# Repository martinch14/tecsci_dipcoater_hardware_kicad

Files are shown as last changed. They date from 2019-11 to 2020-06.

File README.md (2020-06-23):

Diseño de Circuitos Integrados de la Carrera de Especialización en Sistemas Embebidos UBA

El siguiente diseño incluye el circuito integrado TMC5130 de la empresa TRINAMIC para el manejo de motores paso a paso
conectado con el módulo del microcontrolador ESP32D

Martin Abel Gambarotta
8vo Cohorte

Vista 3D:

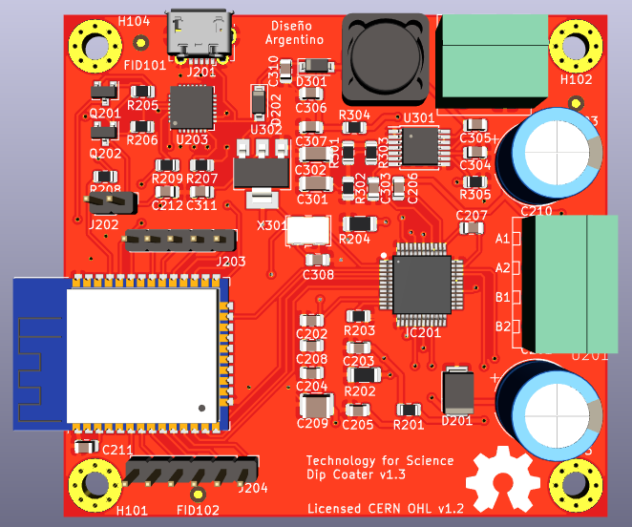
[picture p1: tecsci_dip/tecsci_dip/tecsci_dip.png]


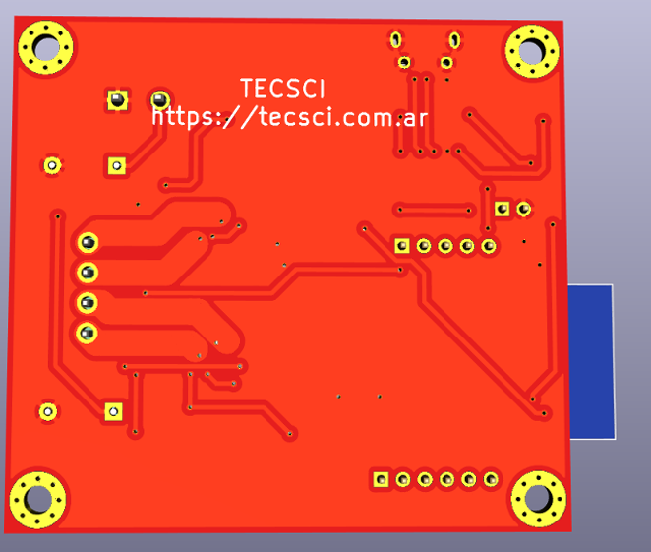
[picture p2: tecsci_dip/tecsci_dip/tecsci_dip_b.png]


Real: Fabricada y montada en Argentina Ernesto Mayer S.A. +  Asembli S.A.

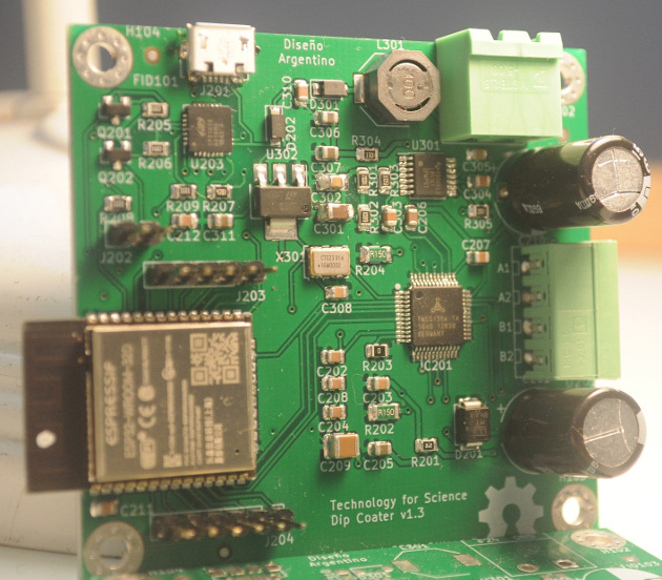
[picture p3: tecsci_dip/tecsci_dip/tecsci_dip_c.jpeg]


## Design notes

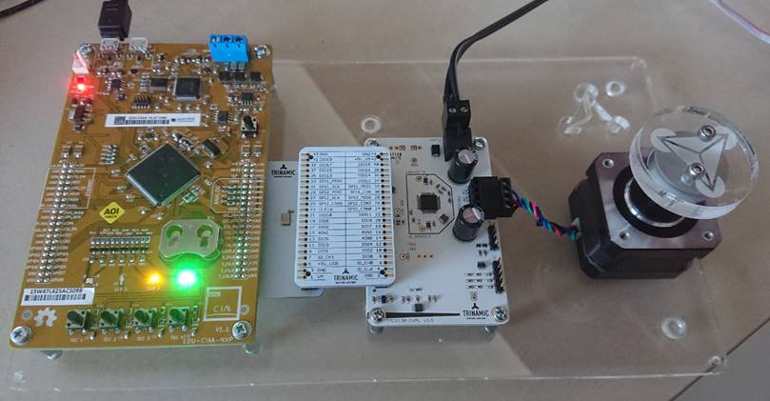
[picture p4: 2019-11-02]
info_propuesta/educiaa+tmc5130.jpg

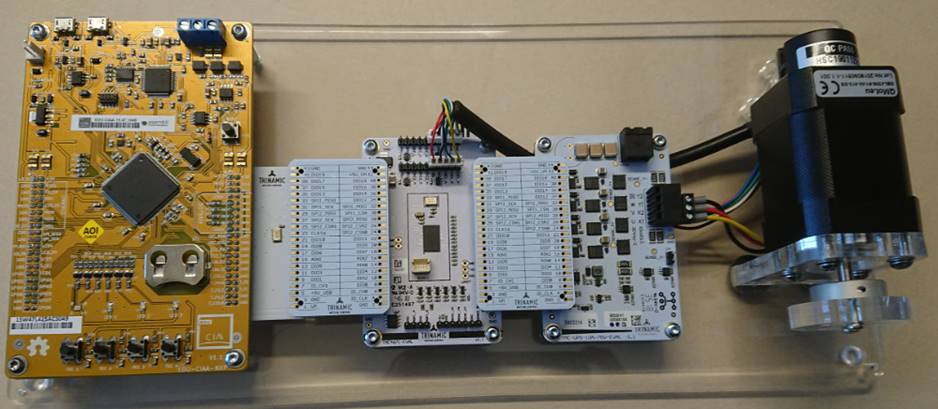
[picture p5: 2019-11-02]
info_propuesta/educiaa+tmc4671.jpg

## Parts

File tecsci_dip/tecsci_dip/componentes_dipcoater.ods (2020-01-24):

Qty | Reference(s) | Value | Footprint | digikey# | manf | manf#
2 | C201, C210 | 150uF/63V | Capacitor_THT:CP_Radial_D10.0mm_P7.50mm | P15406-ND | Panasonic Electronic Components | EEU-FR1J151
4 | C202, C204, C206, C208 | 100nF/50V | Capacitor_SMD:C_0805_2012Metric
1 | C203 | 470nF/16V | Capacitor_SMD:C_0805_2012Metric
1 | C205 | 4.7uF/16V | Capacitor_SMD:C_0805_2012Metric
2 | C207, C303 | 22nF/50V | Capacitor_SMD:C_0805_2012Metric
1 | C209 | 4.7uF/100V | Capacitor_SMD:C_1210_3225Metric
2 | C211, C212 | 0.1uF/10V | Capacitor_SMD:C_0805_2012Metric
1 | C301 | 2.2uF/100V | Capacitor_SMD:C_1206_3216Metric
1 | C302 | 100nF/100V | Capacitor_SMD:C_1206_3216Metric
1 | C304 | 1uF/50V | Capacitor_SMD:C_0805_2012Metric
1 | C305 | 10nF/10V | Capacitor_SMD:C_0805_2012Metric
3 | C306, C307, C311 | 10uF/10V | Capacitor_SMD:C_0805_2012Metric
1 | C308 | 10nF/16V | Capacitor_SMD:C_0805_2012Metric
1 | C310 | 100nF/10V | Capacitor_SMD:C_0805_2012Metric
1 | D201 | SMBJ43A | TMC5130-Eval_v15:SMB | SMBJ43AFSTR-ND | Taiwan Semiconductor Corporation | SMBJ43A
2 | D202, D301 | PMEG3020CEH | Diode_SMD:D_SOD-123 | 1727-3873-2-ND | Nexperia USA Inc. | PMEG3020EH,115
1 | IC201 | TMC5130 | TMC5130-Eval_v15:QFP50P900X900X113-49N_NOFID | 1460-1124-ND | Trinamic Motion Control GmbH | TMC5130A-TA
1 | J201 | USB_B_Micro | Connector_USB:USB_Micro-B_Molex-105017-0001 | WM1399CT-ND
1 | J202 | Boot | Connector_PinHeader_2.54mm:PinHeader_1x02_P2.54mm_Vertical | 5-146285-2-ND
1 | J203 | Conn_01x05 | Connector_PinHeader_2.54mm:PinHeader_1x05_P2.54mm_Vertical | SAM15242-ND
1 | J204 | Conn_01x06 | Connector_PinHeader_2.54mm:PinHeader_1x06_P2.54mm_Vertical | A121372-ND
1 | L301 | SRU8043 | Inductor_SMD:L_Bourns-SRU8043 | SRU8043-100YTR-ND | Bourns Inc. | SRU8043-100Y
1 | POWER_IN301 | POL_HEADER | TMC5130-Eval_v15:AKL349_02_POL | 277-1106-ND
2 | Q201, Q202 | S8050 | Package_TO_SOT_SMD:SOT-23 | MMSS8050-H-TPMSCT-ND
1 | R201 | 2R2/1% | Resistor_SMD:R_0805_2012Metric
2 | R202, R204 | 0R15/1% | Resistor_SMD:R_1206_3216Metric
1 | R203 | 0R/1% | Resistor_SMD:R_0805_2012Metric
2 | R205, R206 | 10K/1% | Resistor_SMD:R_0805_2012Metric
1 | R207 | 4.7K/1% | Resistor_SMD:R_0805_2012Metric
2 | R208, R209 | 1K/1% | Resistor_SMD:R_0805_2012Metric
1 | R301 | 30k/1% | Resistor_SMD:R_0805_2012Metric
1 | R302 | 6.8k/1% | Resistor_SMD:R_0805_2012Metric
1 | R303 | 150k/1% | Resistor_SMD:R_0805_2012Metric
1 | R304 | 3.3k/1% | Resistor_SMD:R_0805_2012Metric
1 | R305 | 2.2k/1% | Resistor_SMD:R_0805_2012Metric
1 | U201 | AKL182_04_POL_HEADER | TMC5130-Eval_v15:AKL169_04_POL | 277-1208-ND
1 | U202 | ESP32-WROOM-32D | RF_Module:ESP32-WROOM-32 | 1904-1023-2-ND
1 | U203 | CP2102N-A01-GQFN28 | Package_DFN_QFN:QFN-28-1EP_5x5mm_P0.5mm_EP3.35x3.35mm | 336-5890-1-ND
1 | U301 | Regulador_LM5161 | Package_SO:TSSOP-14-1EP_4.4x5mm_P0.65mm | 296-47791-2-ND | Texas Instruments | LM5161QPWPRQ1
1 | U302 | LD1117S33TR_SOT223 | Package_TO_SOT_SMD:SOT-223-3_TabPin2 | 497-1242-1-ND
1 | X301 | Oscillator_636L3C016M00000 | Oscillator:Oscillator_SMD_EuroQuartz_XO53-4Pin_5.0x3.2mm | CTX691CT-ND

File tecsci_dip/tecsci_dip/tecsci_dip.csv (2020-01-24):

Source: | /home/martin/Escritorio/KiCadProject/tecsci_dipcoater_github/tecsci_dip/tecsci_dip/tecsci_dip.sch
Date: | vie 24 ene 2020 11:53:21 -03
Tool: | Eeschema 5.1.4-e60b266~84~ubuntu18.04.1
Generator: | /usr/share/kicad/plugins/bom_csv_grouped_by_value.py
Component Count: | 62
Individual Components:
Item | Qty | Reference(s) | Value | LibPart | Footprint | Datasheet | digikey# | manf | manf#
 |  | C201 | 150uF/63V | Device:CP | Capacitor_THT:CP_Radial_D10.0mm_P7.50mm | ~ | P15406-ND | Panasonic Electronic Components | EEU-FR1J151
 |  | C202 | 100nF/50V | Device:C | Capacitor_SMD:C_0805_2012Metric | ~
 |  | C203 | 470nF/16V | Device:C | Capacitor_SMD:C_0805_2012Metric | ~
 |  | C204 | 100nF/50V | Device:C | Capacitor_SMD:C_0805_2012Metric | ~
 |  | C205 | 4.7uF/16V | Device:C | Capacitor_SMD:C_0805_2012Metric | https://api.kemet.com/component-edge/download/datasheet/C0805C475K4RACAUTO.pdf | 399-15711-2-ND | KEMET | C0805C475K4RACAUTO
 |  | C206 | 100nF/50V | Device:C | Capacitor_SMD:C_0805_2012Metric | ~
 |  | C207 | 22nF/50V | Device:C | Capacitor_SMD:C_0805_2012Metric | ~
 |  | C208 | 100nF/50V | Device:C | Capacitor_SMD:C_0805_2012Metric | ~
 |  | C209 | 4.7uF/100V | Device:C | Capacitor_SMD:C_1210_3225Metric | ~
 |  | C210 | 150uF/63V | Device:CP | Capacitor_THT:CP_Radial_D10.0mm_P7.50mm | ~ | P15406-ND | Panasonic Electronic Components | EEU-FR1J151
 |  | C211 | 0.1uF/10V | Device:C | Capacitor_SMD:C_0805_2012Metric | ~
 |  | C212 | 0.1uF/10V | Device:C | Capacitor_SMD:C_0805_2012Metric | ~
 |  | C301 | 2.2uF/100V | Device:C | Capacitor_SMD:C_1206_3216Metric | ~
 |  | C302 | 100nF/100V | Device:C | Capacitor_SMD:C_1206_3216Metric | ~
 |  | C303 | 22nF/50V | Device:C | Capacitor_SMD:C_0805_2012Metric | ~
 |  | C304 | 1uF/50V | Device:C | Capacitor_SMD:C_0805_2012Metric | ~
 |  | C305 | 10nF/10V | Device:C | Capacitor_SMD:C_0805_2012Metric | ~
 |  | C306 | 10uF/10V | Device:C | Capacitor_SMD:C_0805_2012Metric | ~
 |  | C307 | 10uF/10V | Device:C | Capacitor_SMD:C_0805_2012Metric | ~
 |  | C308 | 10nF/16V | Device:C | Capacitor_SMD:C_0805_2012Metric | ~
 |  | C310 | 100nF/10V | Device:C | Capacitor_SMD:C_0805_2012Metric | ~
 |  | C311 | 10uF/10V | Device:C | Capacitor_SMD:C_0805_2012Metric | ~
 |  | D201 | SMBJ43A | TMC5130-Eval_v15-eagle-import:SMBJ | TMC5130-Eval_v15:SMB | https://www.taiwansemi.com/products/datasheet/SMBJ%20SERIES_P1812.pdf | SMBJ43AFSTR-ND | Taiwan Semiconductor Corporation | SMBJ43A
 |  | D202 | PMEG3020CEH | tecsci_dip-cache:PMEG6010CEH | Diode_SMD:D_SOD-123 |  | 1727-3873-2-ND | Nexperia USA Inc. | PMEG3020EH,115
 |  | D301 | PMEG3020CEH | Diode:PMEG6010CEH | Diode_SMD:D_SOD-123 | https://assets.nexperia.com/documents/data-sheet/PMEG6010CEH_PMEG6010CEJ.pdf | 1727-3873-2-ND | Nexperia USA Inc. | PMEG3020EH,115
 |  | FID101 | Fiducial | Mechanical:Fiducial | Fiducial:Fiducial_1mm_Mask2mm | ~
 |  | FID102 | Fiducial | Mechanical:Fiducial | Fiducial:Fiducial_1mm_Mask2mm | ~
 |  | FID103 | Fiducial | Mechanical:Fiducial | Fiducial:Fiducial_1mm_Mask2mm | ~
 |  | H101 | MountingHole | Mechanical:MountingHole | MountingHole:MountingHole_3.2mm_M3_Pad_Via | ~
 |  | H102 | MountingHole | Mechanical:MountingHole | MountingHole:MountingHole_3.2mm_M3_Pad_Via | ~
 |  | H103 | MountingHole | Mechanical:MountingHole | MountingHole:MountingHole_3.2mm_M3_Pad_Via | ~
 |  | H104 | MountingHole | Mechanical:MountingHole | MountingHole:MountingHole_3.2mm_M3_Pad_Via | ~
 |  | IC201 | TMC5130 | TMC5130-Eval_v15-eagle-import:TMC5130 | TMC5130-Eval_v15:QFP50P900X900X113-49N_NOFID | https://www.trinamic.com/_scripts/download.php | 1460-1124-ND | Trinamic Motion Control GmbH | TMC5130A-TA
 |  | J201 | USB_B_Micro | Connector:USB_B_Micro | Connector_USB:USB_Micro-B_Molex-105017-0001 | ~ | WM1399CT-ND
 |  | J202 | Boot | Connector_Generic:Conn_01x02 | Connector_PinHeader_2.54mm:PinHeader_1x02_P2.54mm_Vertical | ~
 |  | J203 | Conn_01x05 | Connector_Generic:Conn_01x05 | Connector_PinHeader_2.54mm:PinHeader_1x05_P2.54mm_Vertical | ~
 |  | J204 | Conn_01x06 | Connector_Generic:Conn_01x06 | Connector_PinHeader_2.54mm:PinHeader_1x06_P2.54mm_Vertical | ~
 |  | L301 | SRU8043 | Ponchobrücke-cache:Device_L_Core_Ferrite | Inductor_SMD:L_Bourns-SRU8043 | https://www.bourns.com/docs/Product-Datasheets/SRU8043.pdf | SRU8043-100YTR-ND | Bourns Inc. | SRU8043-100Y
 |  | OSHWA101 | Logo_Open_Hardware_Small | Graphic:Logo_Open_Hardware_Small | Symbol:OSHW-Symbol_8.9x8mm_SilkScreen | ~
 |  | POWER_IN301 | POL_HEADER | TMC5130-Eval_v15-eagle-import:AKL_349_02_POL_HEADER | TMC5130-Eval_v15:AKL349_02_POL |  | 277-1106-ND
 |  | Q201 | S8050 | Transistor_BJT:S8050 | Package_TO_SOT_SMD:SOT-23 | http://www.unisonic.com.tw/datasheet/S8050.pdf | MMSS8050-H-TPMSCT-ND
 |  | Q202 | S8050 | Transistor_BJT:S8050 | Package_TO_SOT_SMD:SOT-23 | http://www.unisonic.com.tw/datasheet/S8050.pdf | MMSS8050-H-TPMSCT-ND
 |  | R201 | 2R2/1% | Device:R | Resistor_SMD:R_0805_2012Metric | ~
 |  | R202 | 0R15/1% | Device:R | Resistor_SMD:R_1206_3216Metric | ~
 |  | R203 | 0R/1% | Device:R | Resistor_SMD:R_0805_2012Metric | ~
 |  | R204 | 0R15/1% | Device:R | Resistor_SMD:R_1206_3216Metric | ~
 |  | R205 | 10K/1% | Device:R | Resistor_SMD:R_0805_2012Metric | ~
 |  | R206 | 10K/1% | Device:R | Resistor_SMD:R_0805_2012Metric | ~
 |  | R207 | 4.7K/1% | Device:R | Resistor_SMD:R_0805_2012Metric | ~
 |  | R208 | 1K/1% | Device:R | Resistor_SMD:R_0805_2012Metric | ~
 |  | R209 | 1K/1% | Device:R | Resistor_SMD:R_0805_2012Metric | ~
 |  | R301 | 30k/1% | Device:R | Capacitor_SMD:C_0805_2012Metric | ~
 |  | R302 | 6.8k/1% | Device:R | Resistor_SMD:R_0805_2012Metric | ~
 |  | R303 | 150k/1% | Device:R | Resistor_SMD:R_0805_2012Metric | ~
 |  | R304 | 3.3k/1% | Device:R | Resistor_SMD:R_0805_2012Metric | ~
 |  | R305 | 2.2k/1% | Device:R | Resistor_SMD:R_0805_2012Metric | ~
 |  | U201 | AKL182_04_POL_HEADER | TMC5130-Eval_v15-eagle-import:AKL182_04_POL_HEADER | TMC5130-Eval_v15:AKL169_04_POL |  | 277-1208-ND
 |  | U202 | ESP32-WROOM-32D | RF_Module:ESP32-WROOM-32D | RF_Module:ESP32-WROOM-32 | https://www.espressif.com/sites/default/files/documentation/esp32-wroom-32d_esp32-wroom-32u_datasheet_en.pdf | 1904-1023-2-ND
 |  | U203 | CP2102N-A01-GQFN28 | Interface_USB:CP2102N-A01-GQFN28 | Package_DFN_QFN:QFN-28-1EP_5x5mm_P0.5mm_EP3.35x3.35mm | https://www.silabs.com/documents/public/data-sheets/cp2102n-datasheet.pdf | 336-5890-1-ND
 |  | U301 | Regulador_LM5161 | Ponchobrücke-cache:Regulator_Controller_LM5161 | Package_SO:TSSOP-14-1EP_4.4x5mm_P0.65mm | http://www.ti.com/general/docs/suppproductinfo.tsp?distId=10 | 296-47791-2-ND | Texas Instruments | LM5161QPWPRQ1
 |  | U302 | LD1117S33TR_SOT223 | Regulator_Linear:LD1117S33TR_SOT223 | Package_TO_SOT_SMD:SOT-223-3_TabPin2 | http://www.st.com/st-web-ui/static/active/en/resource/technical/document/datasheet/CD00000544.pdf | 497-1242-1-ND
 |  | X301 | Oscillator_636L3C016M00000 | Ponchobrücke-cache:Oscillator_636L3C016M00000 | Oscillator:Oscillator_SMD_EuroQuartz_XO53-4Pin_5.0x3.2mm |  | CTX691CT-ND
Collated Components:
Item | Qty | Reference(s) | Value | LibPart | Footprint | Datasheet | digikey# | manf | manf#
1 | 2 | C201, C210 | 150uF/63V | Device:CP | Capacitor_THT:CP_Radial_D10.0mm_P7.50mm | ~ | P15406-ND | Panasonic Electronic Components | EEU-FR1J151
2 | 4 | C202, C204, C206, C208 | 100nF/50V | Device:C | Capacitor_SMD:C_0805_2012Metric | ~
3 | 1 | C203 | 470nF/16V | Device:C | Capacitor_SMD:C_0805_2012Metric | ~
4 | 1 | C205 | 4.7uF/16V | Device:C | Capacitor_SMD:C_0805_2012Metric | https://api.kemet.com/component-edge/download/datasheet/C0805C475K4RACAUTO.pdf | 399-15711-2-ND | KEMET | C0805C475K4RACAUTO
5 | 2 | C207, C303 | 22nF/50V | Device:C | Capacitor_SMD:C_0805_2012Metric | ~
6 | 1 | C209 | 4.7uF/100V | Device:C | Capacitor_SMD:C_1210_3225Metric | ~
7 | 2 | C211, C212 | 0.1uF/10V | Device:C | Capacitor_SMD:C_0805_2012Metric | ~
8 | 1 | C301 | 2.2uF/100V | Device:C | Capacitor_SMD:C_1206_3216Metric | ~
9 | 1 | C302 | 100nF/100V | Device:C | Capacitor_SMD:C_1206_3216Metric | ~
10 | 1 | C304 | 1uF/50V | Device:C | Capacitor_SMD:C_0805_2012Metric | ~
11 | 1 | C305 | 10nF/10V | Device:C | Capacitor_SMD:C_0805_2012Metric | ~
12 | 3 | C306, C307, C311 | 10uF/10V | Device:C | Capacitor_SMD:C_0805_2012Metric | ~
13 | 1 | C308 | 10nF/16V | Device:C | Capacitor_SMD:C_0805_2012Metric | ~
14 | 1 | C310 | 100nF/10V | Device:C | Capacitor_SMD:C_0805_2012Metric | ~
15 | 1 | D201 | SMBJ43A | TMC5130-Eval_v15-eagle-import:SMBJ | TMC5130-Eval_v15:SMB | https://www.taiwansemi.com/products/datasheet/SMBJ%20SERIES_P1812.pdf | SMBJ43AFSTR-ND | Taiwan Semiconductor Corporation | SMBJ43A
16 | 2 | D202, D301 | PMEG3020CEH | Diode:PMEG6010CEH | Diode_SMD:D_SOD-123 | https://assets.nexperia.com/documents/data-sheet/PMEG6010CEH_PMEG6010CEJ.pdf | 1727-3873-2-ND | Nexperia USA Inc. | PMEG3020EH,115
17 | 3 | FID101, FID102, FID103 | Fiducial | Mechanical:Fiducial | Fiducial:Fiducial_1mm_Mask2mm | ~
18 | 4 | H101, H102, H103, H104 | MountingHole | Mechanical:MountingHole | MountingHole:MountingHole_3.2mm_M3_Pad_Via | ~
19 | 1 | IC201 | TMC5130 | TMC5130-Eval_v15-eagle-import:TMC5130 | TMC5130-Eval_v15:QFP50P900X900X113-49N_NOFID | https://www.trinamic.com/_scripts/download.php | 1460-1124-ND | Trinamic Motion Control GmbH | TMC5130A-TA
20 | 1 | J201 | USB_B_Micro | Connector:USB_B_Micro | Connector_USB:USB_Micro-B_Molex-105017-0001 | ~ | WM1399CT-ND
21 | 1 | J202 | Boot | Connector_Generic:Conn_01x02 | Connector_PinHeader_2.54mm:PinHeader_1x02_P2.54mm_Vertical | ~
22 | 1 | J203 | Conn_01x05 | Connector_Generic:Conn_01x05 | Connector_PinHeader_2.54mm:PinHeader_1x05_P2.54mm_Vertical | ~
23 | 1 | J204 | Conn_01x06 | Connector_Generic:Conn_01x06 | Connector_PinHeader_2.54mm:PinHeader_1x06_P2.54mm_Vertical | ~
24 | 1 | L301 | SRU8043 | Ponchobrücke-cache:Device_L_Core_Ferrite | Inductor_SMD:L_Bourns-SRU8043 | https://www.bourns.com/docs/Product-Datasheets/SRU8043.pdf | SRU8043-100YTR-ND | Bourns Inc. | SRU8043-100Y
25 | 1 | OSHWA101 | Logo_Open_Hardware_Small | Graphic:Logo_Open_Hardware_Small | Symbol:OSHW-Symbol_8.9x8mm_SilkScreen | ~
26 | 1 | POWER_IN301 | POL_HEADER | TMC5130-Eval_v15-eagle-import:AKL_349_02_POL_HEADER | TMC5130-Eval_v15:AKL349_02_POL |  | 277-1106-ND
27 | 2 | Q201, Q202 | S8050 | Transistor_BJT:S8050 | Package_TO_SOT_SMD:SOT-23 | http://www.unisonic.com.tw/datasheet/S8050.pdf | MMSS8050-H-TPMSCT-ND
28 | 1 | R201 | 2R2/1% | Device:R | Resistor_SMD:R_0805_2012Metric | ~
29 | 2 | R202, R204 | 0R15/1% | Device:R | Resistor_SMD:R_1206_3216Metric | ~
30 | 1 | R203 | 0R/1% | Device:R | Resistor_SMD:R_0805_2012Metric | ~
31 | 2 | R205, R206 | 10K/1% | Device:R | Resistor_SMD:R_0805_2012Metric | ~
32 | 1 | R207 | 4.7K/1% | Device:R | Resistor_SMD:R_0805_2012Metric | ~
33 | 2 | R208, R209 | 1K/1% | Device:R | Resistor_SMD:R_0805_2012Metric | ~
34 | 1 | R301 | 30k/1% | Device:R | Capacitor_SMD:C_0805_2012Metric | ~
35 | 1 | R302 | 6.8k/1% | Device:R | Resistor_SMD:R_0805_2012Metric | ~
36 | 1 | R303 | 150k/1% | Device:R | Resistor_SMD:R_0805_2012Metric | ~
37 | 1 | R304 | 3.3k/1% | Device:R | Resistor_SMD:R_0805_2012Metric | ~
38 | 1 | R305 | 2.2k/1% | Device:R | Resistor_SMD:R_0805_2012Metric | ~
39 | 1 | U201 | AKL182_04_POL_HEADER | TMC5130-Eval_v15-eagle-import:AKL182_04_POL_HEADER | TMC5130-Eval_v15:AKL169_04_POL |  | 277-1208-ND
40 | 1 | U202 | ESP32-WROOM-32D | RF_Module:ESP32-WROOM-32D | RF_Module:ESP32-WROOM-32 | https://www.espressif.com/sites/default/files/documentation/esp32-wroom-32d_esp32-wroom-32u_datasheet_en.pdf | 1904-1023-2-ND
41 | 1 | U203 | CP2102N-A01-GQFN28 | Interface_USB:CP2102N-A01-GQFN28 | Package_DFN_QFN:QFN-28-1EP_5x5mm_P0.5mm_EP3.35x3.35mm | https://www.silabs.com/documents/public/data-sheets/cp2102n-datasheet.pdf | 336-5890-1-ND
42 | 1 | U301 | Regulador_LM5161 | Ponchobrücke-cache:Regulator_Controller_LM5161 | Package_SO:TSSOP-14-1EP_4.4x5mm_P0.65mm | http://www.ti.com/general/docs/suppproductinfo.tsp?distId=10 | 296-47791-2-ND | Texas Instruments | LM5161QPWPRQ1
43 | 1 | U302 | LD1117S33TR_SOT223 | Regulator_Linear:LD1117S33TR_SOT223 | Package_TO_SOT_SMD:SOT-223-3_TabPin2 | http://www.st.com/st-web-ui/static/active/en/resource/technical/document/datasheet/CD00000544.pdf | 497-1242-1-ND
44 | 1 | X301 | Oscillator_636L3C016M00000 | Ponchobrücke-cache:Oscillator_636L3C016M00000 | Oscillator:Oscillator_SMD_EuroQuartz_XO53-4Pin_5.0x3.2mm |  | CTX691CT-ND

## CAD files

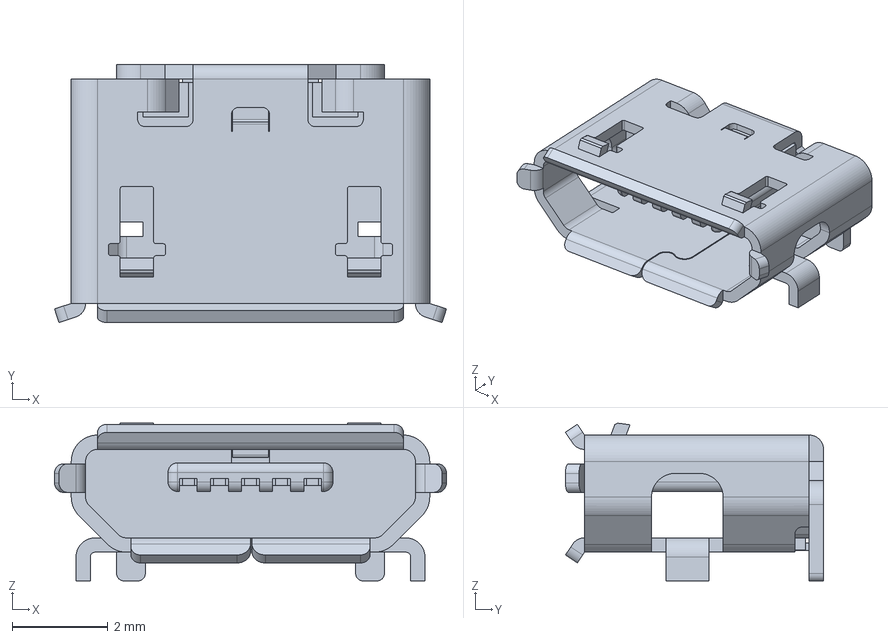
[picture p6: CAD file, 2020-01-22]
tecsci_dip/tecsci_dip/modelos3D/Molex_Mirco_USB_105017-0001.step
8.20 x 5.40 x 3.30 mm

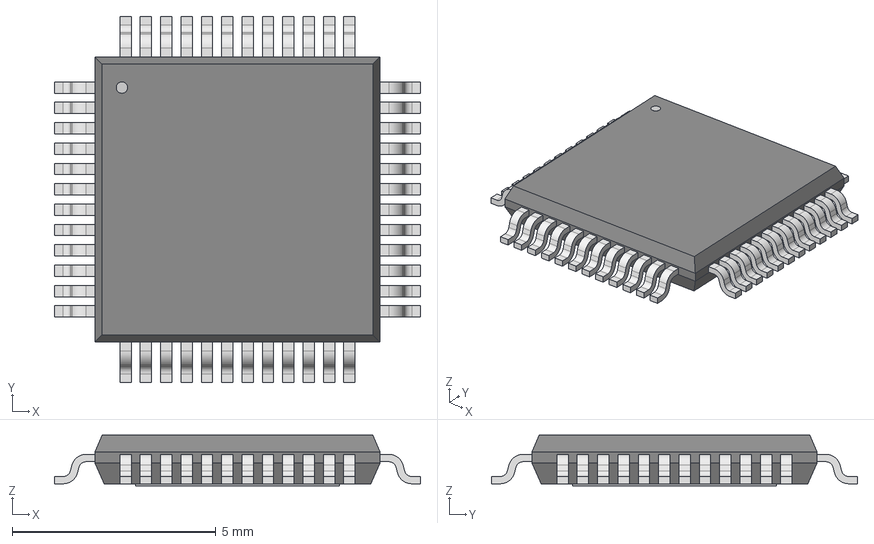
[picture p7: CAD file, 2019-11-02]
tecsci_dip/tecsci_dip/modelos3D/TMC5130eTQFP48_9x9.step
8.99 x 8.99 x 1.25 mm

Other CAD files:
tecsci_dip/tecsci_dip/modelos3D/TMC5130eTQFP48_9x9-L.step
tecsci_dip/tecsci_dip/modelos3D/TMC5130eTQFP48_9x9-M.step

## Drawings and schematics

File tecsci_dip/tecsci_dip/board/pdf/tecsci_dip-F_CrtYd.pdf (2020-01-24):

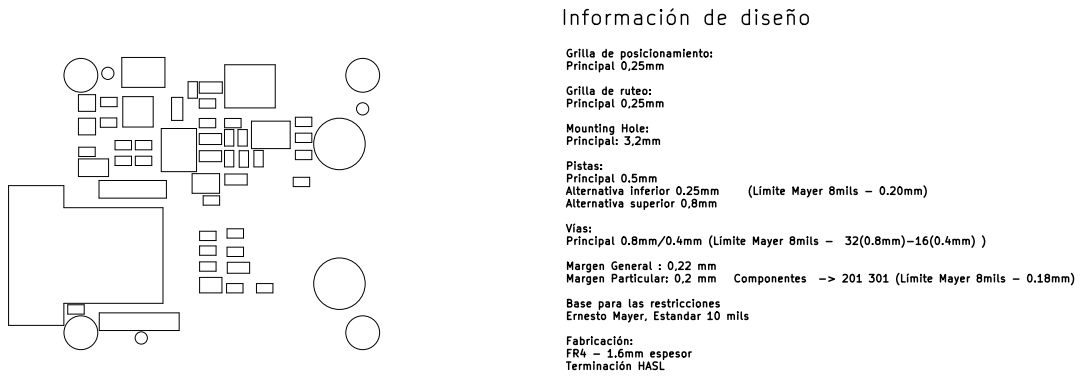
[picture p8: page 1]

Grilla de ruteo: Principal 0,25mm

Alternativa inferior 0.25mm (Límite Mayer 8mils - 0.20mm)
Alternativa superior 0,8mm

Margen General : 0,22 mm
Margen Particular: 0,2 mm Componentes -> 201 301 (Límite Mayer 8mils - 0.18mm)

Base para las restricciones
Ernesto Mayer, Estandar 10 mils

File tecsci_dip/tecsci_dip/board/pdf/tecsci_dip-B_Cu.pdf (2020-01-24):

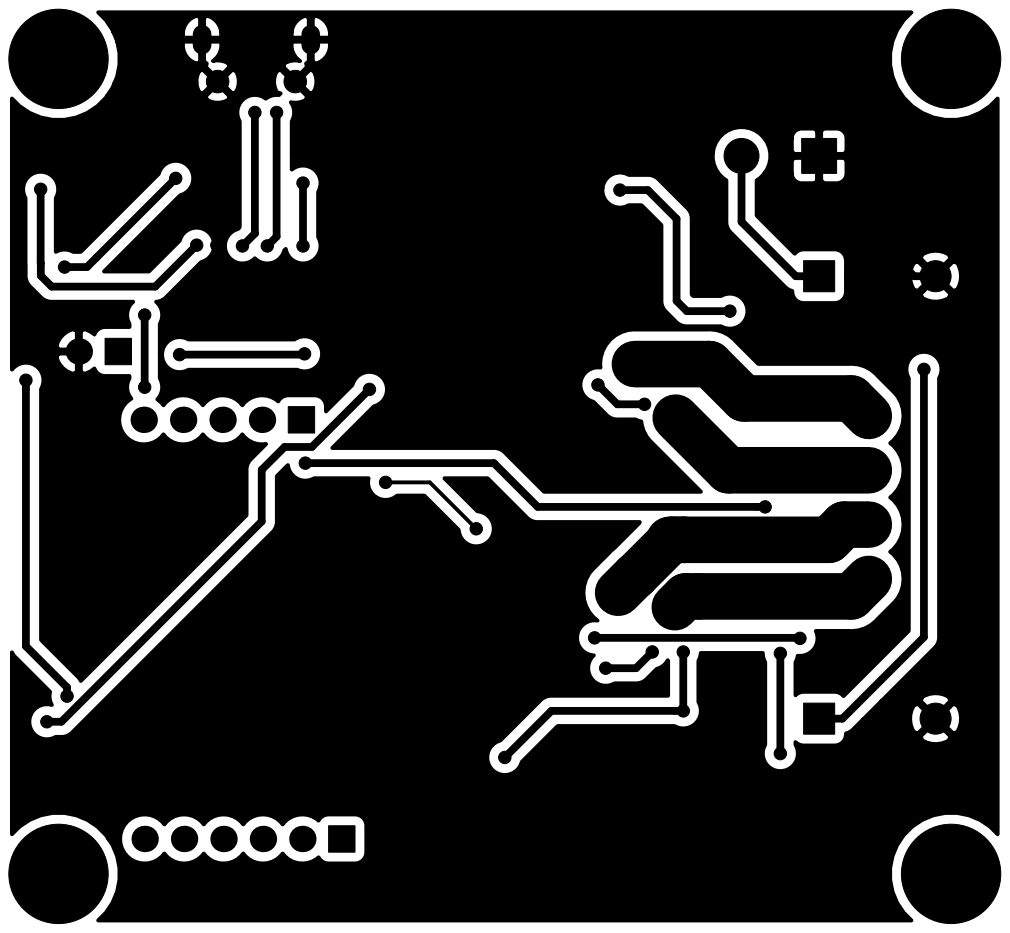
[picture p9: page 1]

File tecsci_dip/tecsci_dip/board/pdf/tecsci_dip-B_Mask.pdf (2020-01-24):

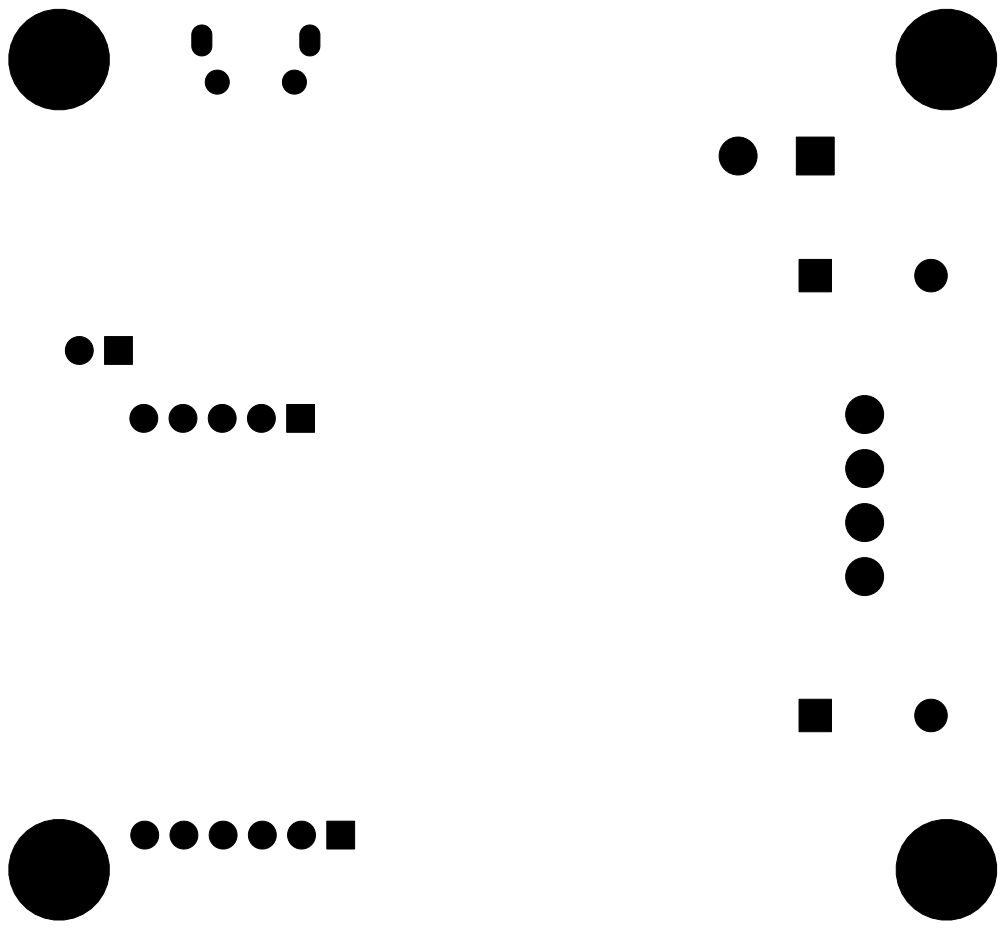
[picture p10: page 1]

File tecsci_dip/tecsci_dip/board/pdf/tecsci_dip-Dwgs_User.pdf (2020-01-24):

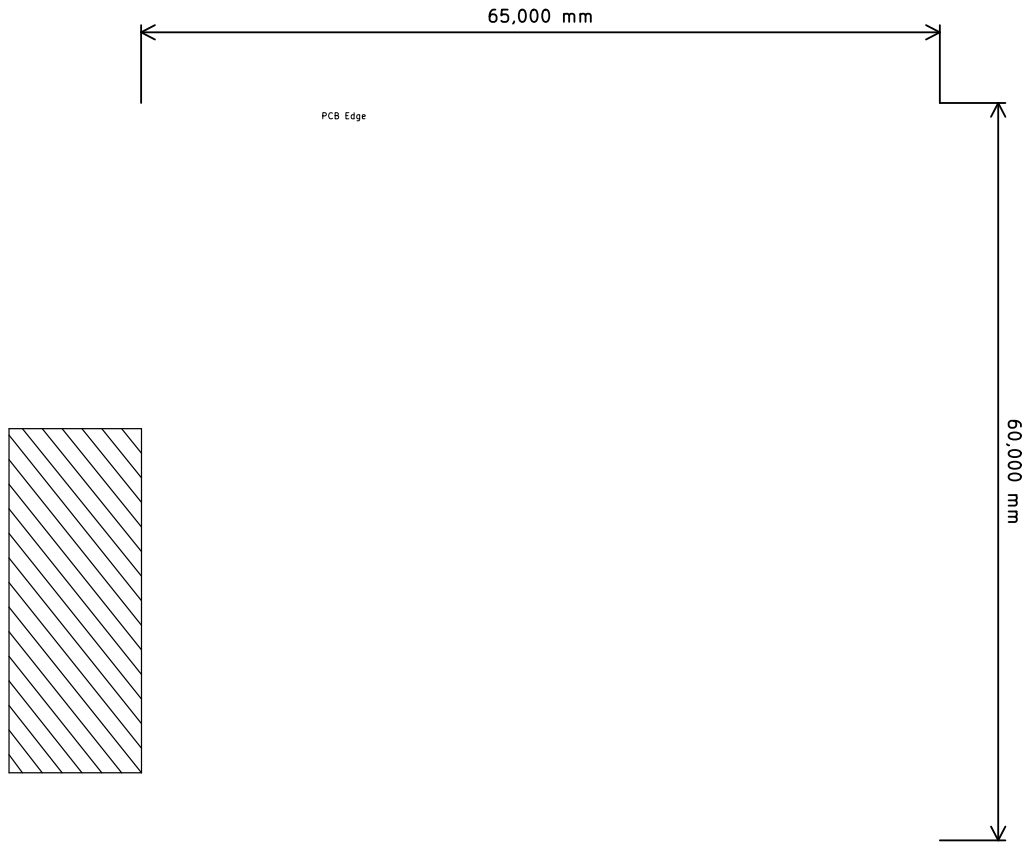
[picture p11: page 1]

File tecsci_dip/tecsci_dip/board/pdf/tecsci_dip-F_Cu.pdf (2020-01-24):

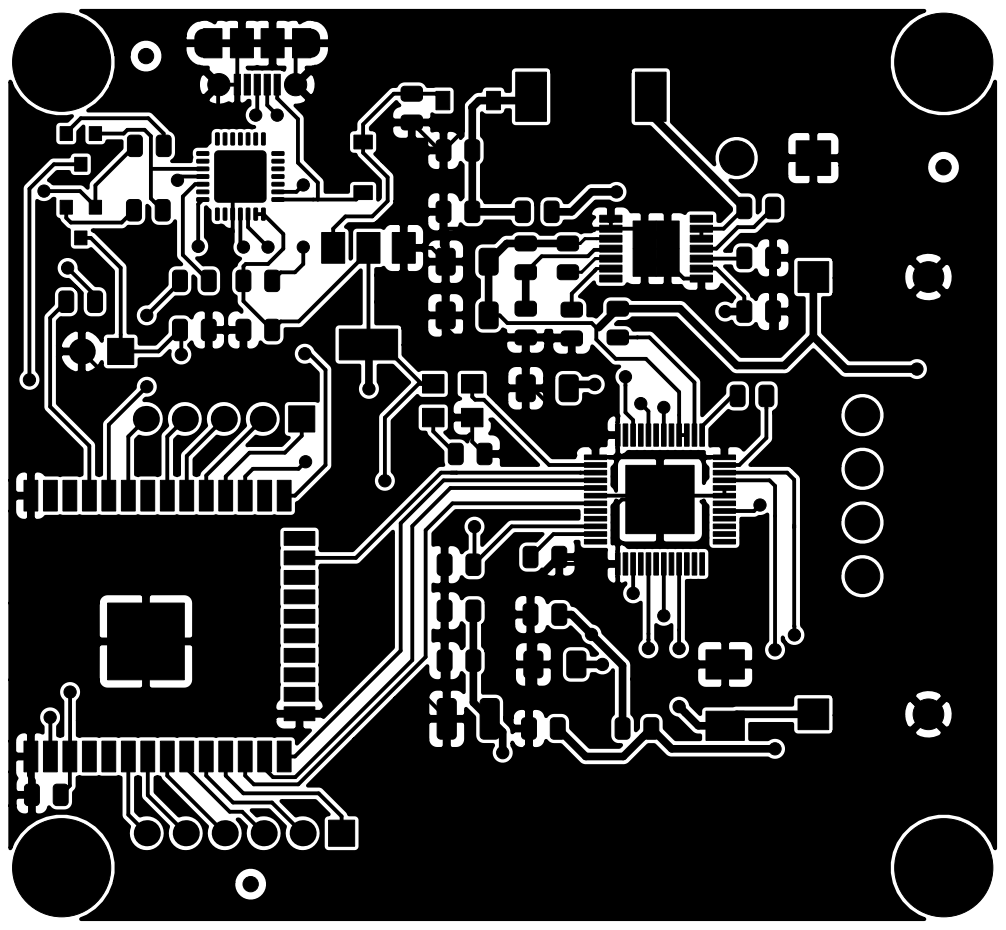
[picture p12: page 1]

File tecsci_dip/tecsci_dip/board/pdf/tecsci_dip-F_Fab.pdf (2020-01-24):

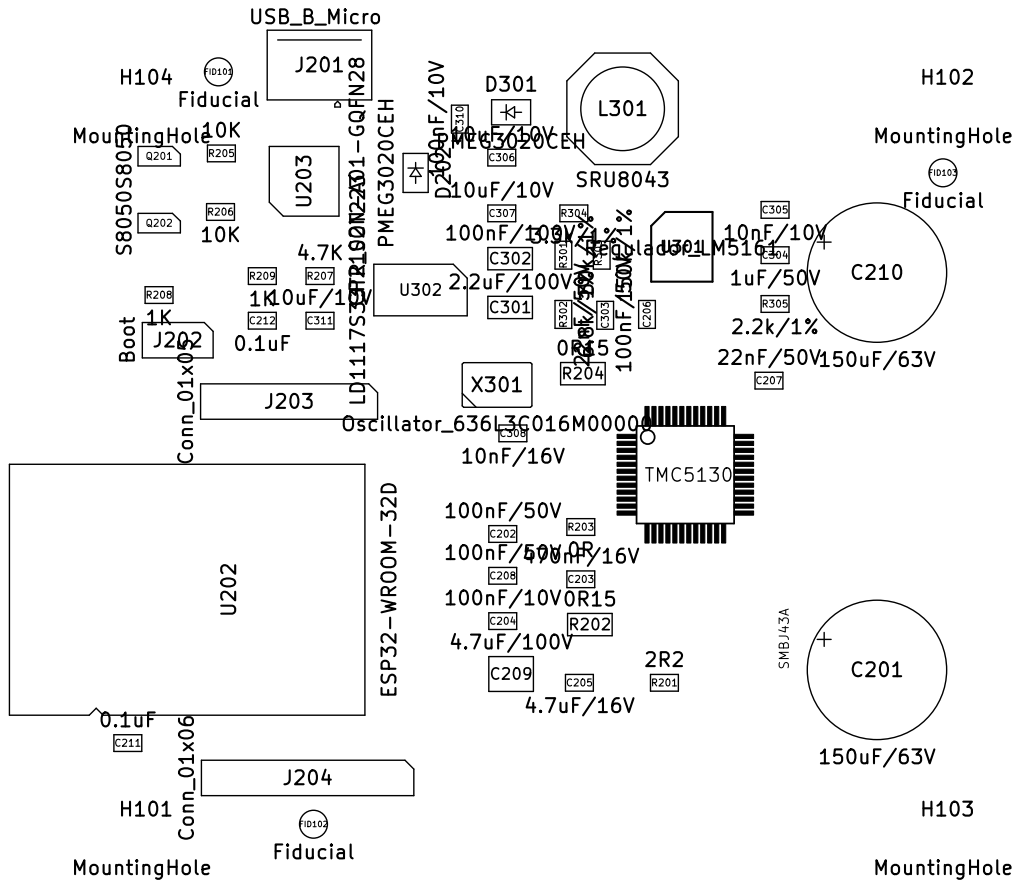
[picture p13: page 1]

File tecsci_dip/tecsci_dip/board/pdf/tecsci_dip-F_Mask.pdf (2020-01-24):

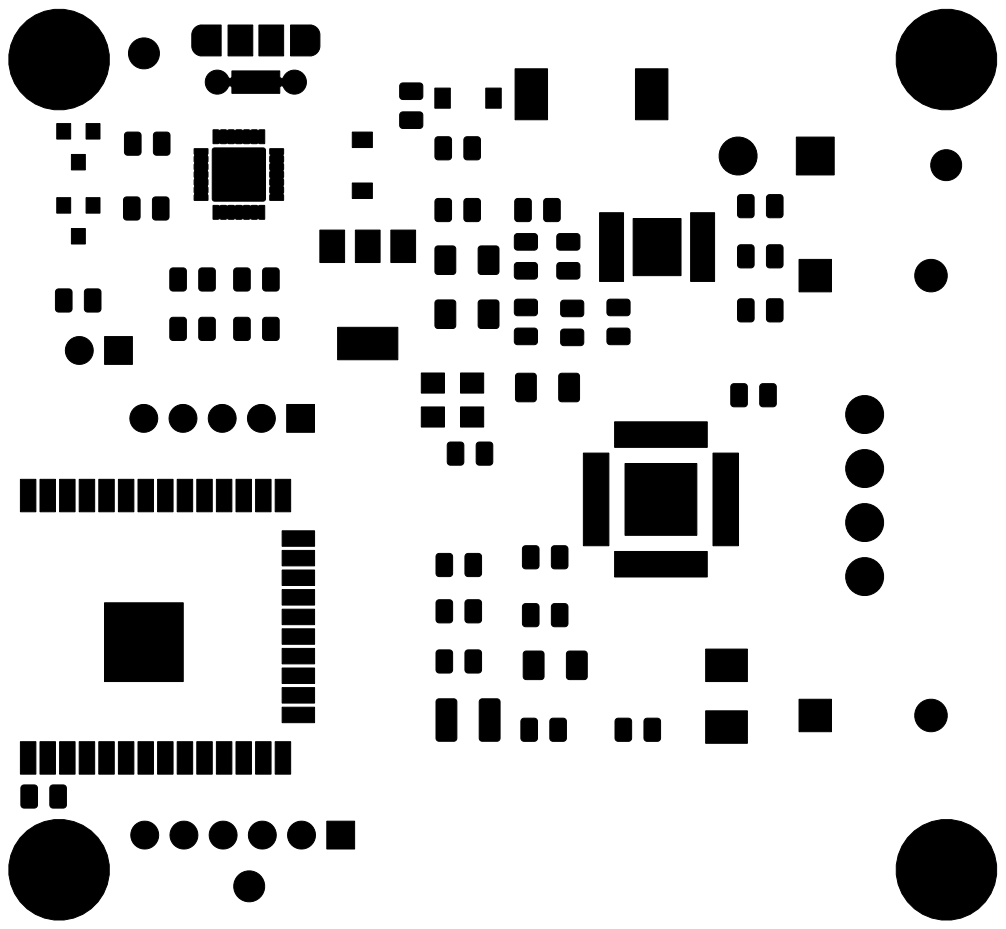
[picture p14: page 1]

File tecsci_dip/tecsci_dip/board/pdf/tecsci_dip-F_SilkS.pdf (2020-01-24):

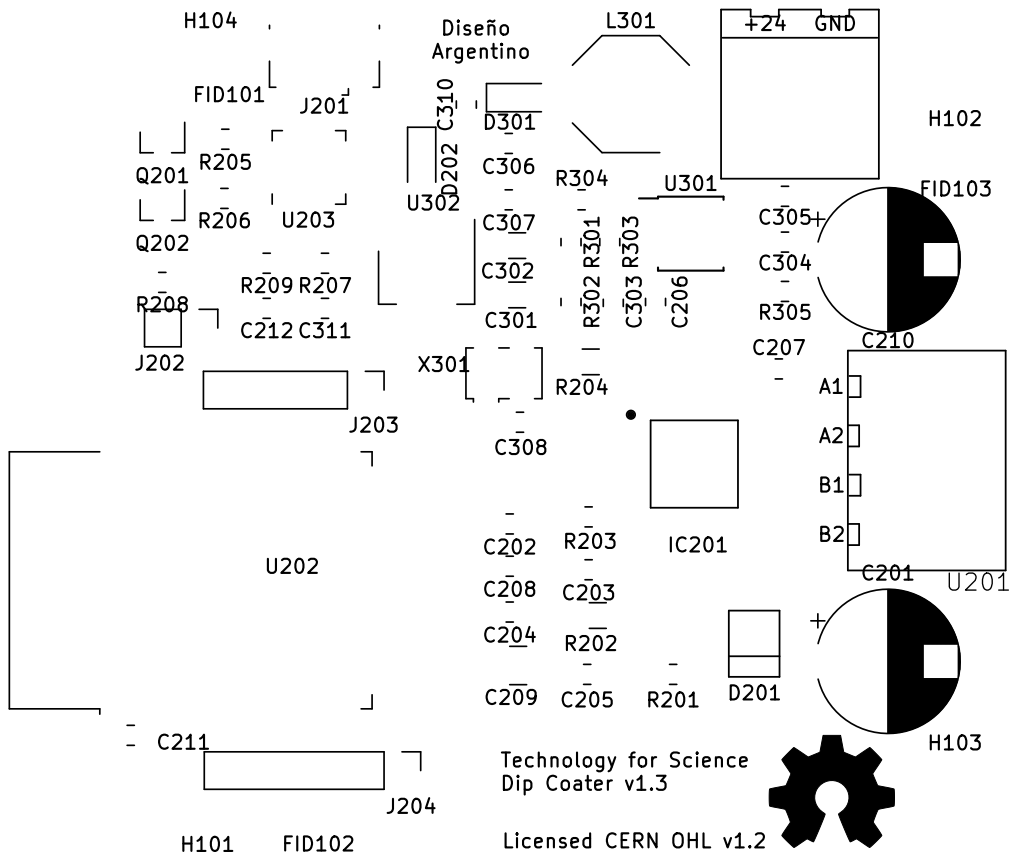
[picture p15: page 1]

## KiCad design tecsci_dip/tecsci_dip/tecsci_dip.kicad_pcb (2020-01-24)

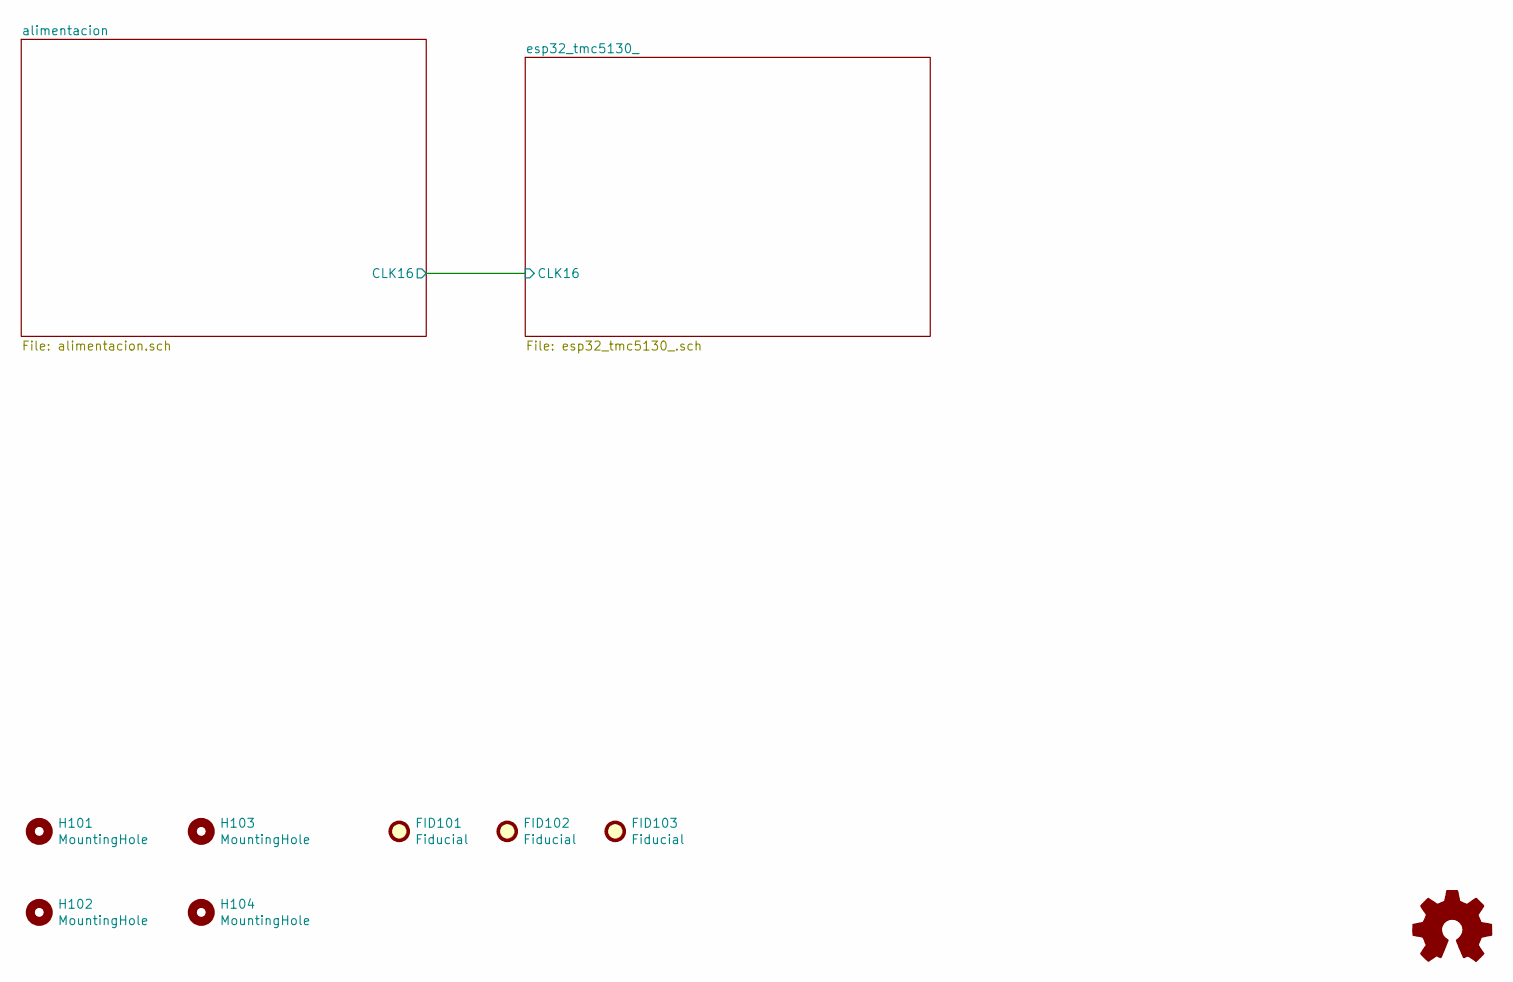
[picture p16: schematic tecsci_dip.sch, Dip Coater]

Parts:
FID101, FID102, FID103: Fiducial; Fiducial_1mm_Mask2mm
H101, H102, H103, H104: MountingHole; MountingHole_3.2mm_M3_Pad_Via
OSHWA101: Logo_Open_Hardware_Small; OSHW-Symbol_8.9x8mm_SilkScreen

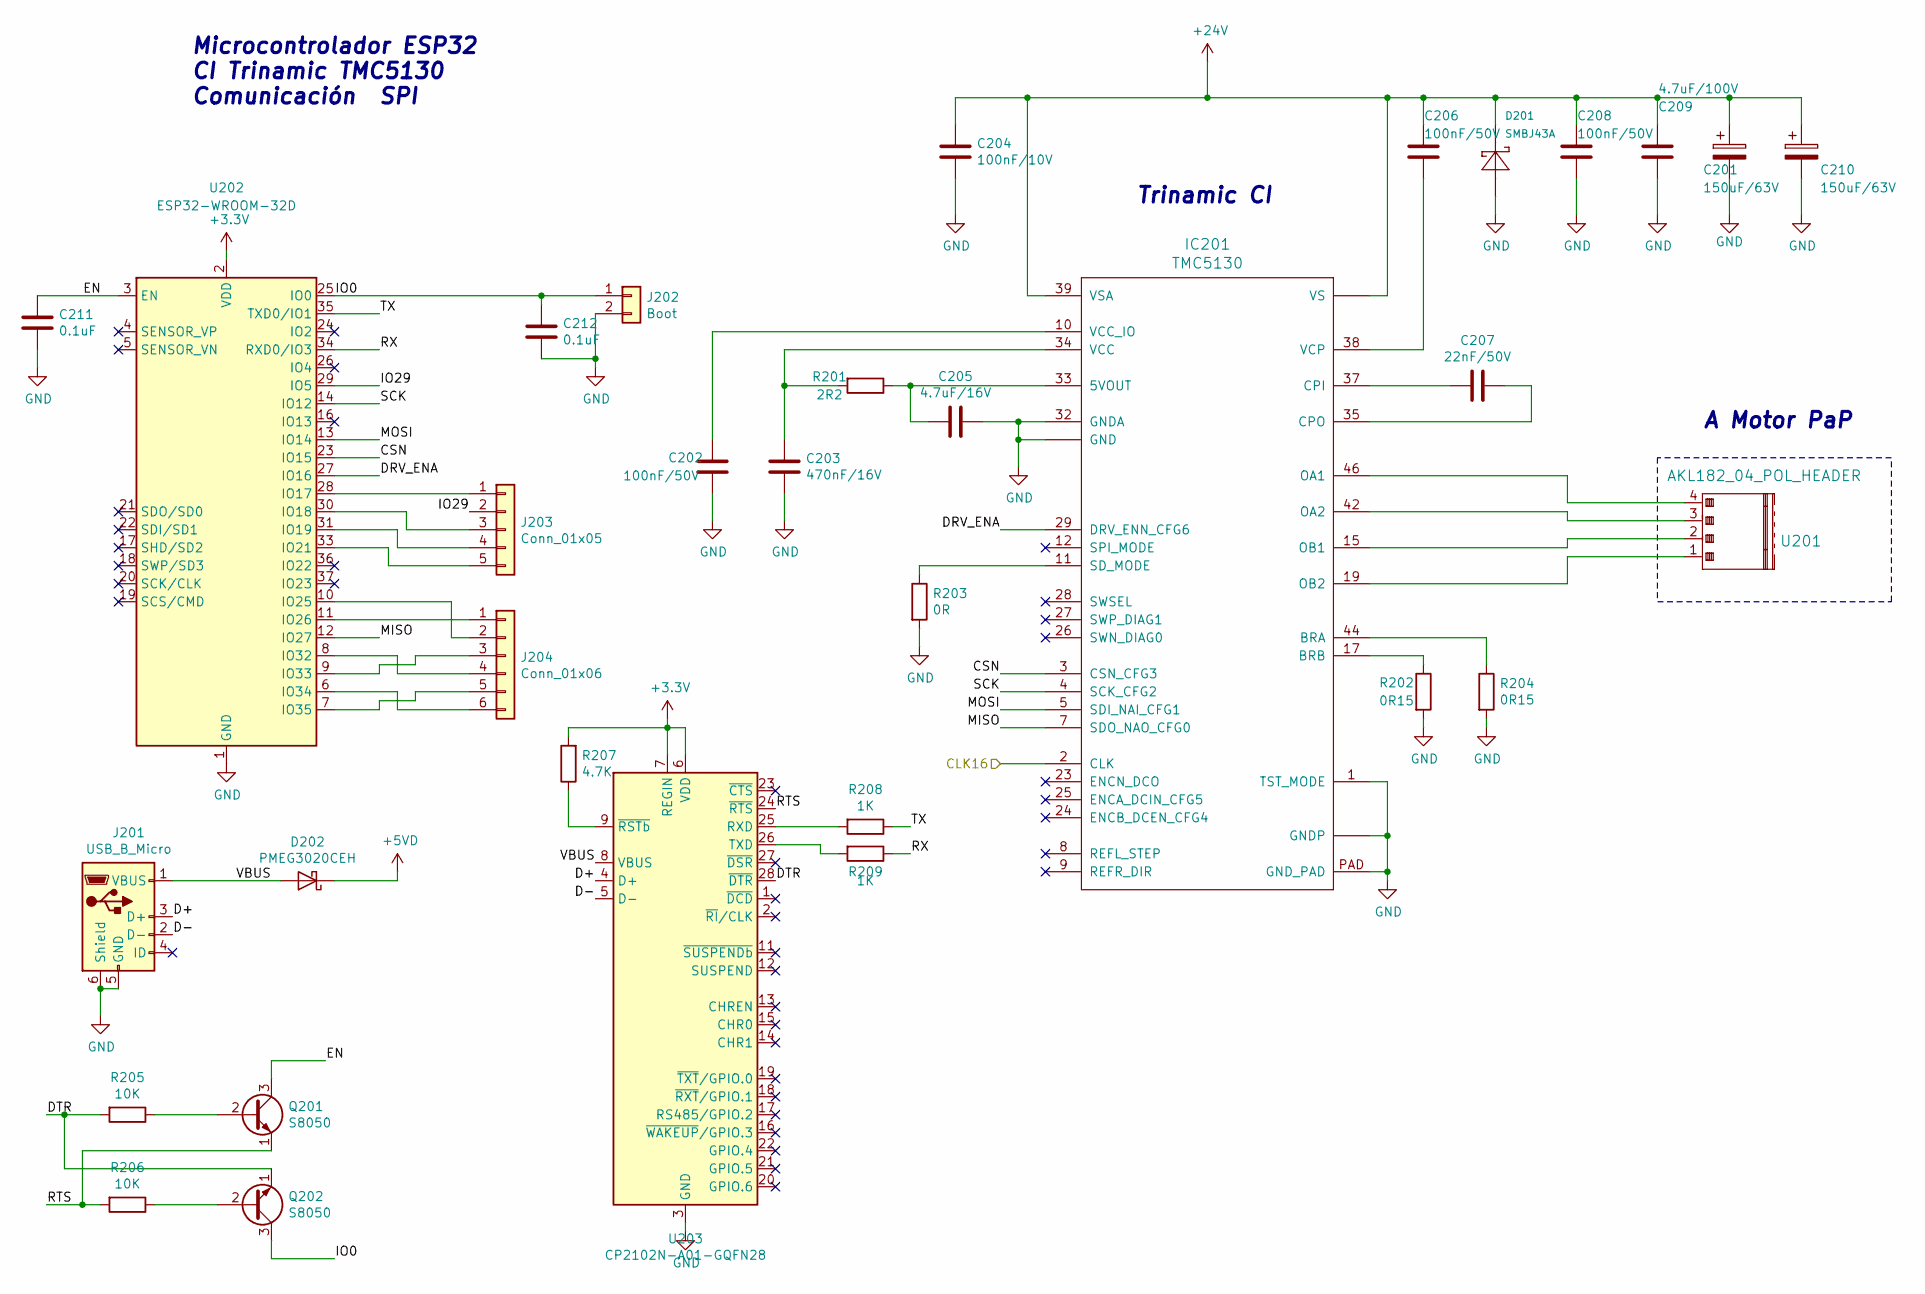
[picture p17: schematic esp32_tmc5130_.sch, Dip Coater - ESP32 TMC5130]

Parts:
C201, C210: 150uF/63V; CP_Radial_D10.0mm_P7.50mm; digikey# P15406-ND
C202, C206, C208: 100nF/50V; C_0805_2012Metric
C203: 470nF/16V; C_0805_2012Metric
C204: 100nF/10V; C_0805_2012Metric
C205: 4.7uF/16V; C_0805_2012Metric; digikey# 399-15711-2-ND
C207: 22nF/50V; C_0805_2012Metric
C209: 4.7uF/100V; C_1210_3225Metric
C211, C212: 0.1uF; C_0805_2012Metric
D201: SMBJ43A; SMB; digikey# SMBJ43AFSTR-ND
D202: PMEG3020CEH; D_SOD-123; digikey# 1727-3873-2-ND
IC201: TMC5130; QFP50P900X900X113-49N_NOFID; digikey# 1460-1124-ND
J201: USB_B_Micro; USB_Micro-B_Molex-105017-0001; digikey# WM1399CT-ND
J202: Boot; PinHeader_1x02_P2.54mm_Vertical
J203: Conn_01x05; PinHeader_1x05_P2.54mm_Vertical
J204: Conn_01x06; PinHeader_1x06_P2.54mm_Vertical
Q201, Q202: S8050; SOT-23; digikey# MMSS8050-H-TPMSCT-ND
R201: 2R2; R_0805_2012Metric
R202, R204: 0R15; R_1206_3216Metric
R203: 0R; R_0805_2012Metric
R205, R206: 10K; R_0805_2012Metric
R207: 4.7K; R_0805_2012Metric
R208, R209: 1K; R_0805_2012Metric
U201: AKL182_04_POL_HEADER; AKL169_04_POL; digikey# 277-1208-ND
U202: ESP32-WROOM-32D; ESP32-WROOM-32; digikey# 1904-1023-2-ND
U203: CP2102N-A01-GQFN28; QFN-28-1EP_5x5mm_P0.5mm_EP3.35x3.35mm; digikey# 336-5890-1-ND

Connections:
+5VD: D202.1 (K); also elsewhere on the board
+24V: C201.1, C204.1, C206.1, C208.1, C209.1, C210.1, D201.C, IC201.21 (VS), IC201.39 (VSA), IC201.40 (VS); also elsewhere on the board
/alimentacion/CLK16: IC201.2 (CLK); also elsewhere on the board
/esp32_tmc5130_/CSN: IC201.3 (CSN_CFG3), U202.23 (IO15)
/esp32_tmc5130_/D+: J201.3 (D+), U203.4 (D+)
/esp32_tmc5130_/D-: J201.2 (D-), U203.5 (D-)
/esp32_tmc5130_/DRV_ENA: IC201.29 (DRV_ENN_CFG6), U202.27 (IO16)
/esp32_tmc5130_/DTR: Q202.1 (E), R205.2, U203.28 (~DTR)
/esp32_tmc5130_/EN: C211.1, Q201.3 (C), U202.3 (EN)
/esp32_tmc5130_/IO0: C212.1, J202.1, Q202.3 (C), U202.25 (IO0)
/esp32_tmc5130_/IO29: J203.2, U202.29 (IO5)
/esp32_tmc5130_/MISO: IC201.7 (SDO_NAO_CFG0), U202.12 (IO27)
/esp32_tmc5130_/MOSI: IC201.5 (SDI_NAI_CFG1), U202.13 (IO14)
/esp32_tmc5130_/RTS: Q201.1 (E), R206.2, U203.24 (~RTS)
/esp32_tmc5130_/RX: R209.1, U202.34 (RXD0/IO3)
/esp32_tmc5130_/SCK: IC201.4 (SCK_CFG2), U202.14 (IO12)
/esp32_tmc5130_/TX: R208.1, U202.35 (TXD0/IO1)
/esp32_tmc5130_/VBUS: D202.2 (A), J201.1 (VBUS), U203.8 (VBUS)
GND: C201.2, C202.2, C203.2, C204.2, C205.1, C208.2, C209.2, C210.2, C211.2, C212.2, D201.A, IC201.1 (TST_MODE), IC201.6 (GND), IC201.13 (GNDP), IC201.31 (GND), IC201.32 (GNDA), IC201.36 (GND), IC201.48 (GNDP), IC201.PAD (GND_PAD), J201.5 (GND), J201.6 (Shield), J202.2, R202.2, R203.2, R204.2, U202.1 (GND), U202.15 (GND), U202.38 (GND), U203.3 (GND), U203.29 (GND); also elsewhere on the board
unnamed: C203.1, IC201.34 (VCC), R201.2
unnamed: C205.2, IC201.33 (5VOUT), R201.1
unnamed: C206.2, IC201.38 (VCP)
unnamed: C207.1, IC201.35 (CPO)
unnamed: C207.2, IC201.37 (CPI)
unnamed: IC201.11 (SD_MODE), R203.1
unnamed: IC201.15 (OB1), U201.2
unnamed: IC201.17 (BRB), R202.1
unnamed: IC201.19 (OB2), U201.1
unnamed: IC201.42 (OA2), U201.3
unnamed: IC201.44 (BRA), R204.1
unnamed: IC201.46 (OA1), U201.4
unnamed: J203.1, U202.28 (IO17)
unnamed: J203.3, U202.30 (IO18)
unnamed: J203.4, U202.31 (IO19)
unnamed: J203.5, U202.33 (IO21)
unnamed: J204.1, U202.11 (IO26)
unnamed: J204.2, U202.10 (IO25)
unnamed: J204.3, U202.9 (IO33)
unnamed: J204.4, U202.8 (IO32)
unnamed: J204.5, U202.7 (IO35)
unnamed: J204.6, U202.6 (IO34)
unnamed: Q201.2 (B), R205.1
unnamed: Q202.2 (B), R206.1
unnamed: R207.1, U203.9 (~RSTb)
unnamed: R208.2, U203.25 (RXD)
unnamed: R209.2, U203.26 (TXD)

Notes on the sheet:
Trinamic CI
A Motor PaP
Microcontrolador ESP32 CI Trinamic TMC5130 Comunicación SPI

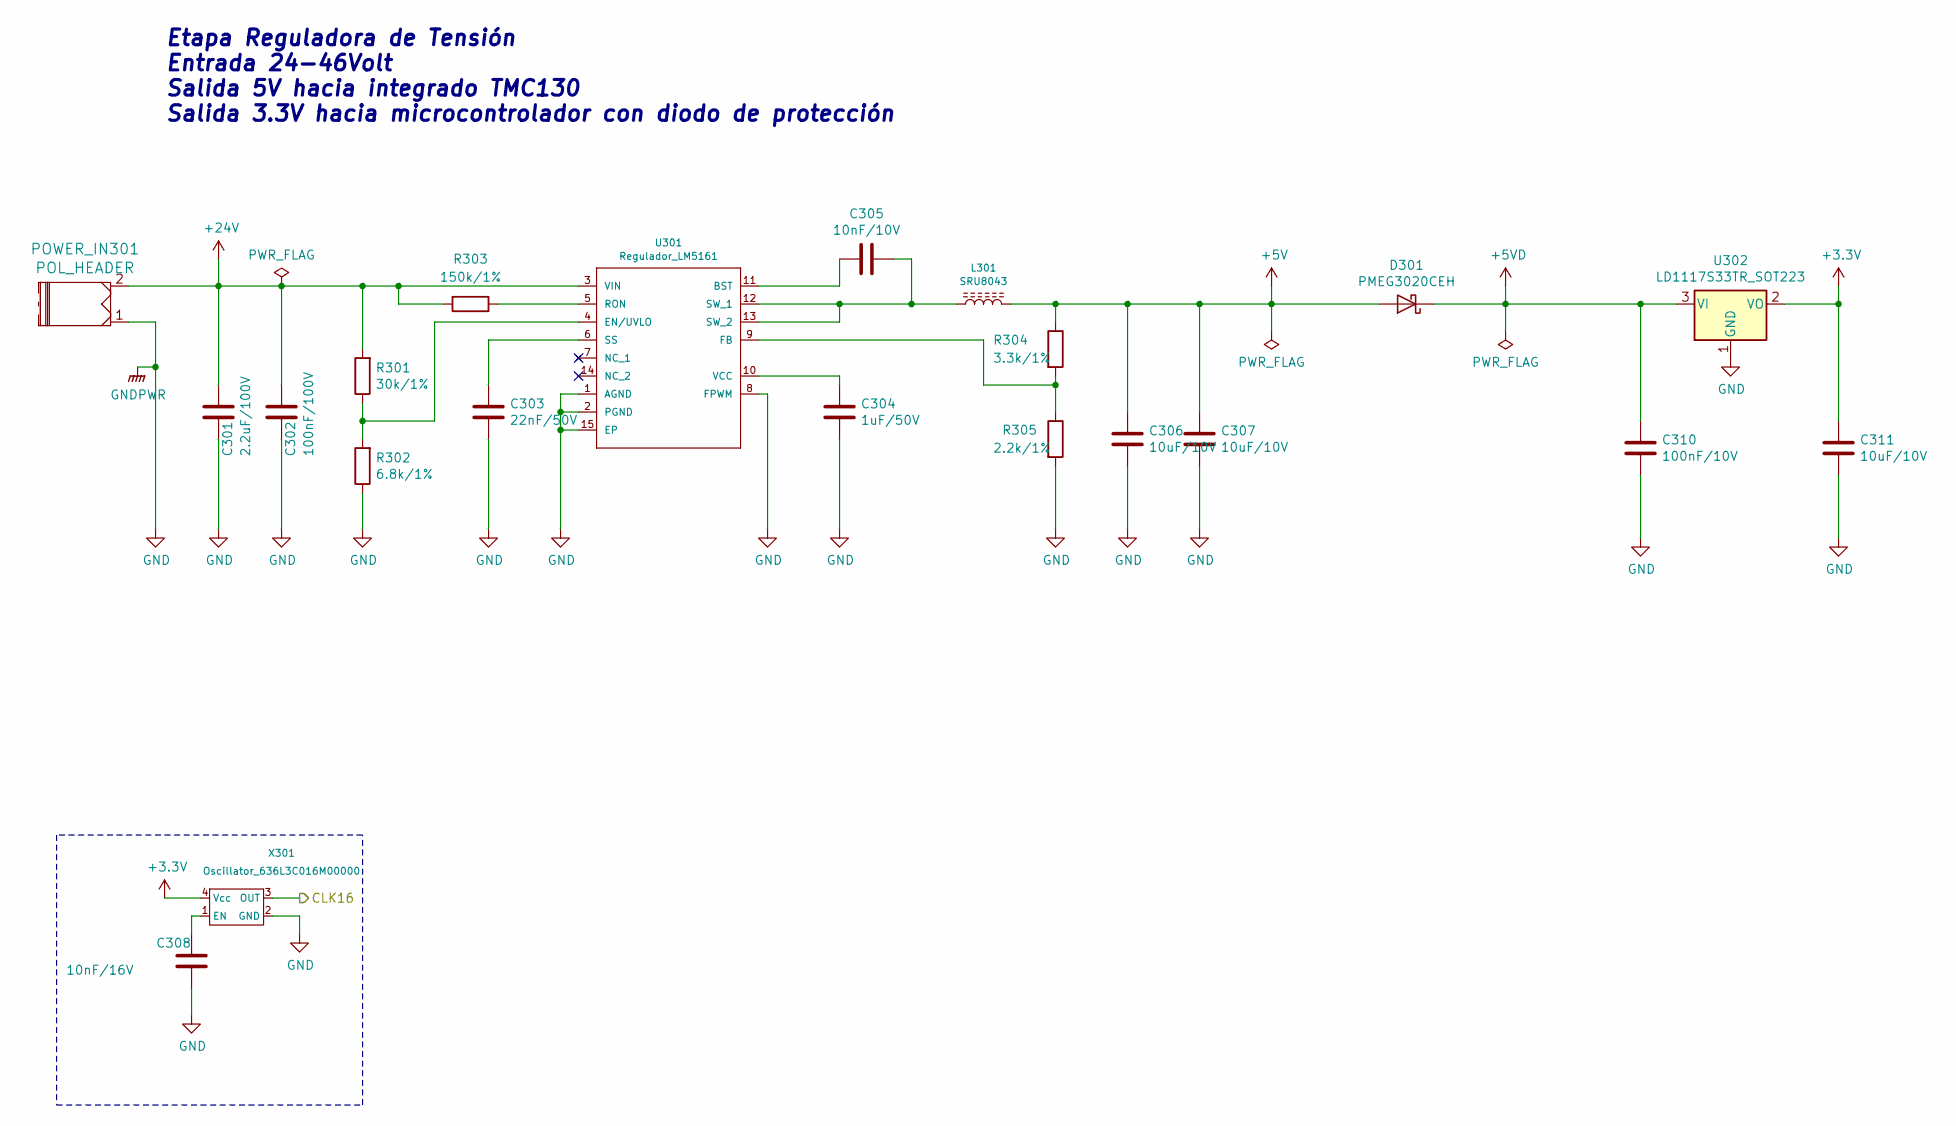
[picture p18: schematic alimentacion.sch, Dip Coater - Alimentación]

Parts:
C301: 2.2uF/100V; C_1206_3216Metric
C302: 100nF/100V; C_1206_3216Metric
C303: 22nF/50V; C_0805_2012Metric
C304: 1uF/50V; C_0805_2012Metric
C305: 10nF/10V; C_0805_2012Metric
C306, C307, C311: 10uF/10V; C_0805_2012Metric
C308: 10nF/16V; C_0805_2012Metric
C310: 100nF/10V; C_0805_2012Metric
D301: PMEG3020CEH; D_SOD-123; digikey# 1727-3873-2-ND
L301: SRU8043; L_Bourns-SRU8043; digikey# SRU8043-100YTR-ND
POWER_IN301: POL_HEADER; AKL349_02_POL; digikey# 277-1106-ND
R301: 30k/1%; R_0805_2012Metric
R302: 6.8k/1%; R_0805_2012Metric
R303: 150k/1%; R_0805_2012Metric
R304: 3.3k/1%; R_0805_2012Metric
R305: 2.2k/1%; R_0805_2012Metric
U301: Regulador_LM5161; TSSOP-14-1EP_4.4x5mm_P0.65mm; digikey# 296-47791-2-ND
U302: LD1117S33TR_SOT223; SOT-223-3_TabPin2; digikey# 497-1242-1-ND
X301: Oscillator_636L3C016M00000; Oscillator_SMD_EuroQuartz_XO53-4Pin_5.0x3.2mm; digikey# CTX691CT-ND

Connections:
+5V: C306.1, C307.1, D301.2 (A), L301.2, R304.1
+5VD: C310.1, D301.1 (K), U302.3 (VI); also elsewhere on the board
+24V: C301.1, C302.1, POWER_IN301.2, R301.2, R303.2, U301.3 (VIN); also elsewhere on the board
/alimentacion/CLK16: X301.3 (OUT); also elsewhere on the board
GND: C301.2, C302.2, C303.2, C304.2, C306.2, C307.2, C308.2, C310.2, C311.2, POWER_IN301.1, R302.1, R305.2, U301.1 (AGND), U301.2 (PGND), U301.8 (FPWM), U301.15 (EP), U302.1 (GND), X301.2 (GND); also elsewhere on the board
unnamed: C303.1, U301.6 (SS)
unnamed: C304.1, U301.10 (VCC)
unnamed: C305.1, L301.1, U301.12 (SW_1), U301.13 (SW_2)
unnamed: C305.2, U301.11 (BST)
unnamed: C308.1, X301.1 (EN)
unnamed: R301.1, R302.2, U301.4 (EN/UVLO)
unnamed: R303.1, U301.5 (RON)
unnamed: R304.2, R305.1, U301.9 (FB)

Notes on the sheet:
Etapa Reguladora de Tensión Entrada 24-46Volt Salida 5V hacia integrado TMC130 Salida 3.3V hacia microcontrolador con diodo de protección

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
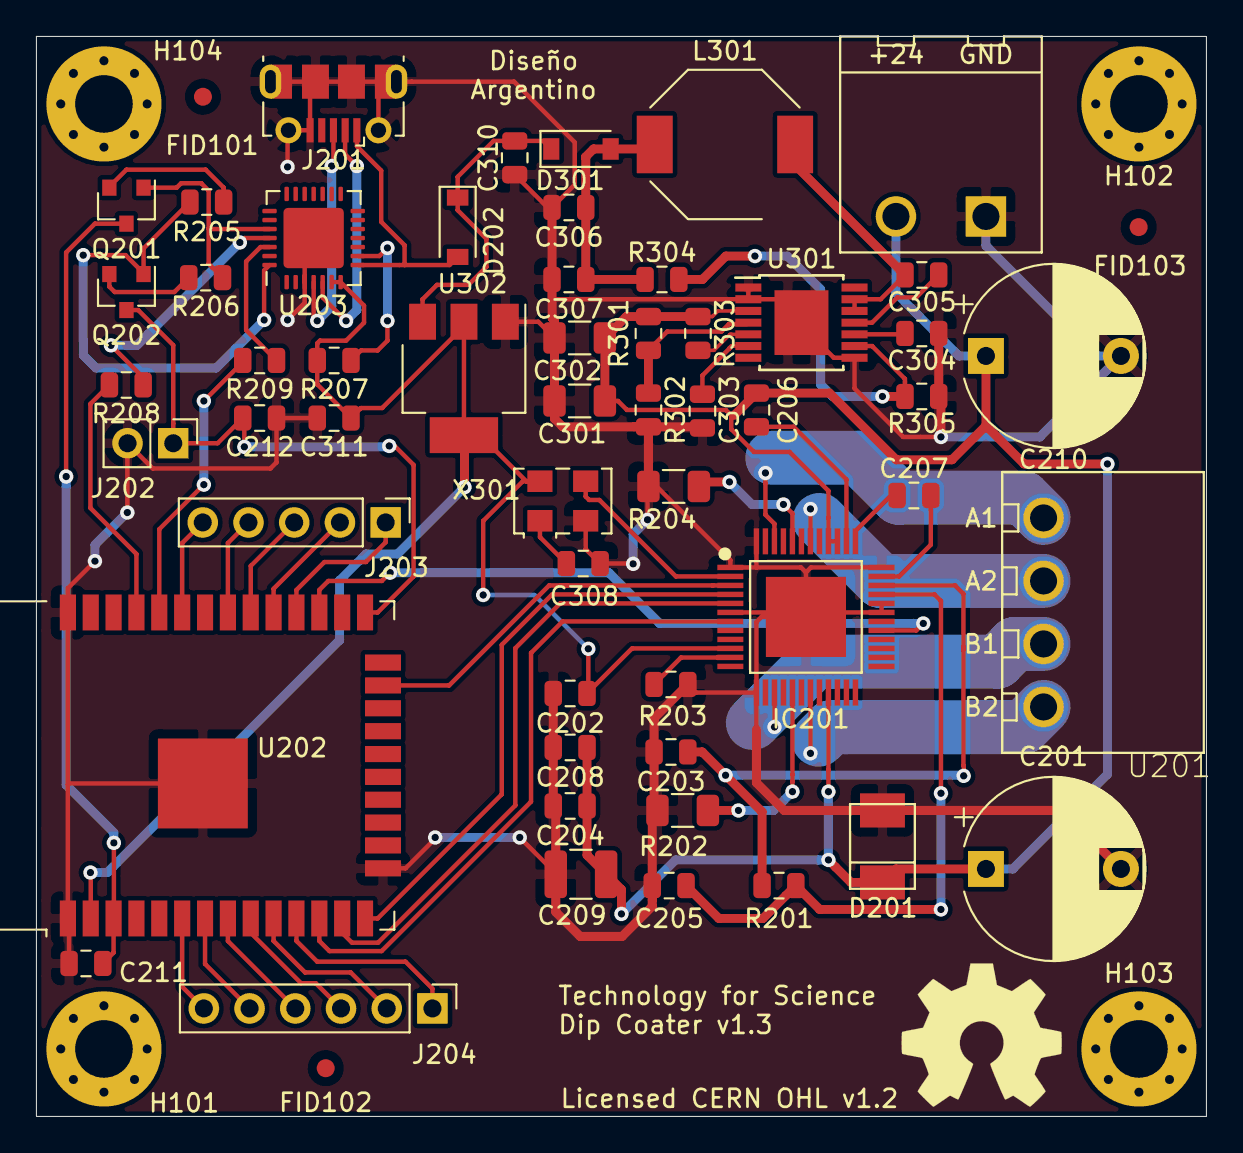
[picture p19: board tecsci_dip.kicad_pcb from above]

Board: 2 copper layers, 65.0 x 60.0 mm, 62 parts (0 on the bottom side), 56 nets.

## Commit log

2020-01-22 version 1.3
    [Molex_Mirco_USB_105017-0001.step, alimentacion.sch, esp32_tmc5130.sch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]
2020-01-24 version fabricada
    [alimentacion.sch, componentes_dipcoater.ods, componentes_dipcoater.xlsx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]

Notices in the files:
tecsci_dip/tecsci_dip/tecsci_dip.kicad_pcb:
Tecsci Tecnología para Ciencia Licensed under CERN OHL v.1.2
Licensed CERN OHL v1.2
